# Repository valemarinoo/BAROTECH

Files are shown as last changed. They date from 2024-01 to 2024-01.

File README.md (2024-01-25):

# BAROTECH PROJECT README

Welcome to the Barotech Project! This repository contains essential files and documentation for the development of a Low Power, Low Cost BLE (Bluetooth Low Energy) device designed for Barometric Pressure monitoring. Below is a guide on the contents of this repository and how to navigate through them.

## Folder Structure:

### 1. Allegro folder
- **.brd file:** PCB layout design file for the Barotech device.

### 2. Capture_CIS folder
- **OrCAD circuit schematics:** Schematic diagrams created in OrCAD Capture CIS for the circuit.

### 3. Eurocircuits folder
- **Validation and Evaluation files:** Provided by Eurocircuits for project cost analysis. Includes files for 1, 10, 100, and 1000 PCBs.

### 4. Gerber folder
- **Gerber files:** Files exported from Allegro for manufacturing validation and evaluation.

### 5. MY_ORCAD_LIBRARY folder
- **Library files:** Used for the symbols in the project.

### 6. PADSTACKS folder
- **.pad files:** Created/modified for the components' padstacks.

### 7. FOOTPRINTS folder
- **.dra files:** Created/modified for the components' footprints.

### 8. Schematics folder
- **PDFs:** OrCAD circuit schematic exported from Capture CIS.

### 9. BOM
- **Excel file:** Project's Bill Of Material, detailing each used component (vendor details, value, mounting type, manufacturer, unit price).

### 10. MOVIE
- **Video:** A brief video providing an overview of the Barotech Project and demonstrating the usage of the main tools.

### 11. Technical_Report
- **Technical report:** Detailed documentation covering the project's design history, features, and final implementation.

## How to Use:

1. **PCB Layout:** Open the .brd file in the Allegro folder for the PCB layout.

2. **Circuit Schematics:** Review the OrCAD circuit schematics in the Capture_CIS folder.

3. **Validation and Evaluation:** Explore the Eurocircuits folder for files required for manufacturing validation and cost analysis.

4. **Gerber Files:** Access manufacturing files in the Gerber folder exported from Allegro.

5. **Library Files:** Find symbol library files in the MY_ORCAD_LIBRARY folder.

6. **PADSTACKS and FOOTPRINTS:** Explore .pad and .dra files in the respective folders for component padstacks and footprints.

7. **Schematic PDFs:** View the exported OrCAD circuit schematic PDFs in the Schematics folder.

8. **Bill Of Material:** Open the BOM Excel file for detailed information on each used component.

9. **Video:** Watch the MOVIE for a brief overview of the project and tool usage.

10. **Technical Report:** Refer to the Technical_Report for a comprehensive understanding of the project's design and implementation.

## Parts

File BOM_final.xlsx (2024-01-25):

Item # | Quantity Per Board | Manufacturer Part # | Do Not Install | Reference Designators | Vendor | Vendor Part Number | Value | Mounting type | Part Description | Manufacturer | UNIT PRICE
1 | 1 | / | / | A1 | / | / | 50 Ohms | / | 50 Ohm Antenna | /
2 | 8 | KGM32HR72D104KU | / | C1,C2,C6,C7,C9,C11,C12,C18,C22 | Digikey | 478-KGM32HR72D104KUTR-ND | 100nF | SMD | Multilayer Ceramic Capacitors MLCC - SMD/SMT 200V .1uF X7R 1210 10% | KYOCERA AVX | 0.49 €
3 | 3 | KGM32ER71H105KU | / | C3,C16,C17 | Digikey | 478-KGM32ER71H105KUTR-ND | 1uF | SMD | Multilayer Ceramic Capacitors MLCC - SMD/SMT 50V 1uF X7R 1210 10% | KYOCERA AVX | 0.41 €
4 | 3 | KGQ32DCG2A120KT | / | C4,C5,C15 | Mouser | 581-12101U120KAT2A | 12pF | SMD | Multilayer Ceramic Capacitors MLCC - SMD/SMT 100V 12pF C0G 1210 10% | KYOCERA AVX | 0.50 €
5 | 4 | KGM32LR71E106KU | / | C8,C10,C19,C21 | Digikey | 478-KGM32LR71E106KUTR-ND | 10uF | SMD | Multilayer Ceramic Capacitors MLCC - SMD/SMT 25V 10uF X7R 1210 10% | KYOCERA AVX | 0.70 €
6 | 2 | C1210C129D8HACTU | / | C13,C14 | Mouser | 80-C1210C129D8HACTU | 1.2pF | SMD | Multilayer Ceramic Capacitors MLCC - SMD/SMT 10V 1.2pF X8R 1210 0.5pF | KEMET | 0.18 €
7 | 1 | C1210C334K5RAC7800 | / | C20 | Digikey | C1210C334K5RAC7800 | 330nF | SMD | Multilayer Ceramic Capacitors MLCC - SMD/SMT .33UF 50V 10% 1210 | KEMET | 0.60 €
8 | 1 | 19-337C/RSBHGHC-A88/4T | / | D1 | Digikey | 1080-1631-2-ND | LED RGB | SMD | LED RGB CLEAR 6SMD | Everlight Electronics Co Ltd | 0.59 €
9 | 1 | BLM18HE152SN1D | / | FB1 | Digikey | 490-5216-2-ND | BLM18HE152SN1D | SMD | Ferrite Beads 1500 Ohm 25% SMD | Murata Electronics | 0.17 €
10 | 1 | BMP390 | / | IC1 | Mouser | 262-BMP390 | BMP390 | SMD | Board Mount Barometric Pressure Sensor High Performance | Bosch Sensortec | 3.67 €
11 | 1 | MAX1759EUB+ | / | IC2 | Digikey | MAX1759EUB+-ND | MAX1759EUB+ | SMD | Switching Voltage Regulators Buck/Boost Regulating Charge Pump in MAX | Maxim Integrated | 6.91 €
12 | 1 | FTSH-105-01-L-D-RA-K | / | J1 | Digikey | SAM9437-ND | FTSH-105-01-L-D-RA-K | SMD | Connector Header Through Hole, Right Angle 10 position 0.050" (1.27mm) | Samtec Inc. | 1.77 €
13 | 1 | B2B-PH-K-S | / | J2 | Digikey | 455-1704-ND | B2B-PH-K-S | SMD | Connector Header Through Hole 2 position 0.079" (2.00mm) | JST Sales America Inc. | 0.17 €
14 | 1 | 1051640001 | / | J3 | Digikey | WM11263TR-ND | 105164-0001 | SMD | micro B USB 2.0 Receptacle Connector 5 Position Surface Mount, Right Angle; Through Hole | Molex | 0.94 €
15 | 1 | BRL3225T100K | / | L1 | Digikey | 587-2167-2-ND | 10uH | SMD | Fixed inductor 10uH 700mA 420mOhm SMD | Taiyo Yuden | 0.20 €
16 | 1 | NLV32T-015J-EF | / | L2 | Digikey | 445-16528-2-ND | 15nH | SMD | RF Inductors - SMD 15nH 160mohms 450mA Wound Ferrite | TDK Corporation | 0.20 €
17 | 1 | LQG15HN2N0S02D | / | L3 | Digikey | 490-6558-2-ND | 2nH | SMD | RF Inductors - SMD 2 NH +-.3NH | Murata Electronics | 0.09 €
18 | 2 | CRCW121010K0JNEA | / | R1,R2,R4 | Digikey | 541-10KVTR-ND | 10 kOhm | SMD | Thick Film Resistors - SMD 1/2watt 10Kohms 5% | Vishay Dale | 0.20 €
19 | 1 | CRCW1210100KFKEA | / | R3 | Digikey | 541-100KAATR-ND | 100 kOhm | SMD | Thick Film Resistors - SMD 1/2watt 100Kohms 1% | Vishay Dale | 0.23 €
20 | 2 | CRCW12103K30JNEA | / | R14 | Digikey | 541-3.3KVTR-ND | 3.3 kOhm | SMD | Thick Film Resistors - SMD 1/2watt 3.3Kohms 5% | Vishay Dale | 0.20 €
21 | 4 | CRCW121033K0JNEA | / | R5,R6,R7,R8 | Digikey | 541-33KVTR-ND | 33 kOhm | SMD | Thick Film Resistors - SMD 1/2watt 33Kohms 5% | Vishay Dale | 0.20 €
22 | 1 | CRCW1210200RFKEA | / | R9 | Digikey | 541-200AATR-ND | 200 Ohm | SMD | Thick Film Resistors - SMD 1/2watt 200ohms 1% | Vishay Dale | 0.23 €
23 | 1 | CRCW121082R0JNEA | / | R10 | Digikey | 541-82VTR-ND | 82 Ohm | SMD | Thick Film Resistors - SMD 1/2watt 82ohms 5% | Vishay Dale | 0.20 €
24 | 1 | CRCW1210110RJNEA | / | R11 | Digikey | 541-CRCW1210110RJNEATR-ND | 110 Ohm | SMD | Thick Film Resistors - SMD 1/2watt 110ohms 5% | Vishay Dale | 0.20 €
25 | 2 | CRCW121022R0JNEA | / | R12,R13 | Digikey | 541-22VTR-ND | 22 Ohm | SMD | Thick Film Resistors - SMD 1/2watt 22ohms 5% | Vishay Dale | 0.20 €
26 | 1 | CRCW1210330RFKEA | / | R15 | Digikey | 541-330AATR-ND | 330 Ohm | SMD | Thick Film Resistors - SMD 1/2watt 330ohms 1% | Vishay Dale | 0.23 €
27 | 1 | LL3301NF065QG | / | S1 | Digikey | EG5897TR-ND | LL3301NF065QG | SMD | Tactile Switches 50mA 12VDC F065 4.3mm Gull Wing | E-Switch | 0.67 €
28 | 1 | TL3901AGQF180 | / | S2 | Digikey | EG6068TR-ND | TL3901AGQF180 | SMD | Tactile Switches TactSwtch 12VDC 50mA | E-Switch | 0.95 €
29 | 1 | CC2640R2FRHBR | / | U1 | Digikey | 296-47317-2-ND | CC2640R2FRHBR | SMD | RF Microcontrollers - SimpleLink™ 32-bit Arm® Cortex®-M3 Bluetooth® 5.1 Low Energy wireless | Texas Instruments | 4.62 €
30 | 1 | MAX1555EZK+T | / | U2 | Digikey | MAX1555EZK+TTR-ND | MAX1555EZK+T | SMD | Battery Management SOT23, Dual-Input, USB/AC Adapter, 1-Cell Li+ Battery Chargers | Maxim Integrated | 2.45 €
31 | 1 | MAX17048G+T10 | / | U3 | Digikey | MAX17048G+T10TR-ND | MAX17048G+T10 | SMD | Battery Management 3 A 1-Cell/2-Cell Fuel Gauge with ModelGauge | Maxim Integrated | 3.09 €
32 | 1 | SC32S-7PF20PPM | / | Y1 | Digikey | 728-1074-2-ND | 32.768 kHz | SMD | 32.768 kHz ±20ppm Crystal 7pF 70 kOhms 2-SMD, No Lead | Seiko Instruments | 0.35 €
33 | 1 | XRCGB24M000F3M00R0 | / | Y2 | Digikey | 490-5576-2-ND | 24MHz | SMD | 24 MHz ±30ppm Crystal 6pF 150 Ohms 4-SMD, No Lead | Murata Electronics | 0.28 €
33 | 1 | L502030 | / | - | TME | ACCU-LP502030/CL | 250mAh | / | Rechargable Li-Po battery: 3.7V; 250mAh; cables,JST SYR-02T socket | Cellevia Batteries | 4.79 €
 |  |  |  |  |  |  |  |  |  |  | TOTALE
 |  |  |  |  |  |  |  |  |  |  | 36.68 €

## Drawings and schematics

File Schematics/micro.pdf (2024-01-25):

## MICROCONTROLLER

# U1 CC2640R2FRHBR

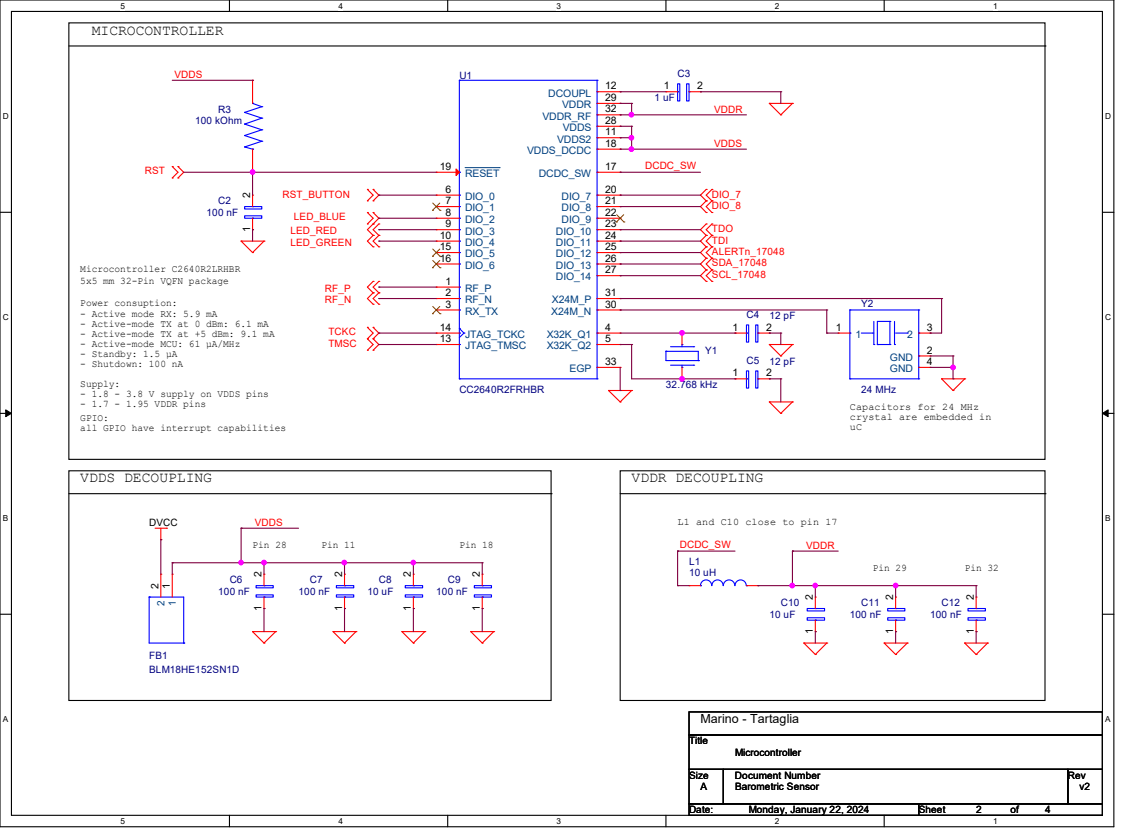
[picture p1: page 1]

Microcontroller C2640R2LRHBR
5x5 mm 32-Pin VQFN package

Power consuption:
- Active mode RX: 5.9 mA
- Active-mode TX at 0 dBm: 6.1 mA
- Active-mode TX at +5 dBm: 9.1 mA
- Active-mode MCU: 61 µA/MHz
- Standby: 1.5 µA
- Shutdown: 100 nA
Supply:
- 1.8 - 3.8 V supply on VDDS pins
- 1.7 - 1.95 VDDR pins
GPIO:
all GPIO have interrupt capabilities DVCC

Capacitors for 24 MHz
crystal are embedded in

L1 and C10 close to pin 17

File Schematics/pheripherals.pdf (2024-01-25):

## ANTENNA

### Antenna for single ended operations

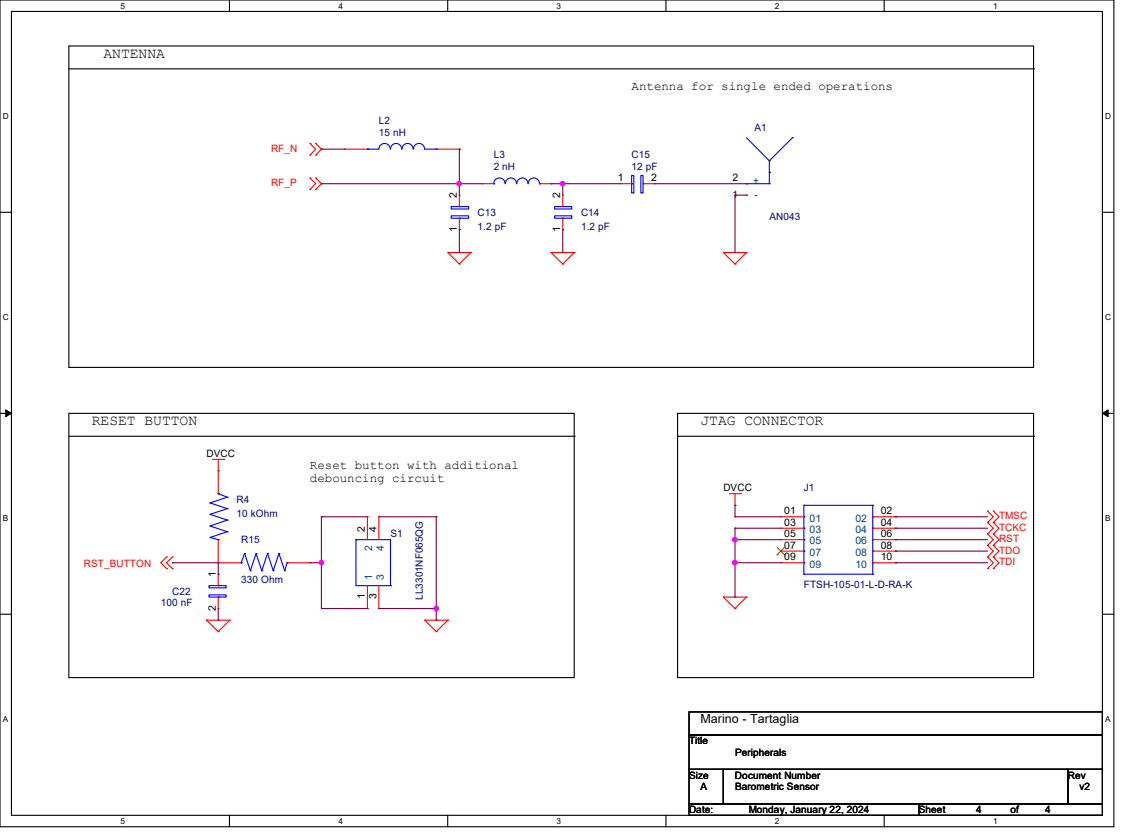
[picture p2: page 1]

Reset button with additional
debouncing circuit

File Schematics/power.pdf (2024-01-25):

## BATTERY CONNECTOR

BATTERY CHARGER | Vf of RGB LED is:

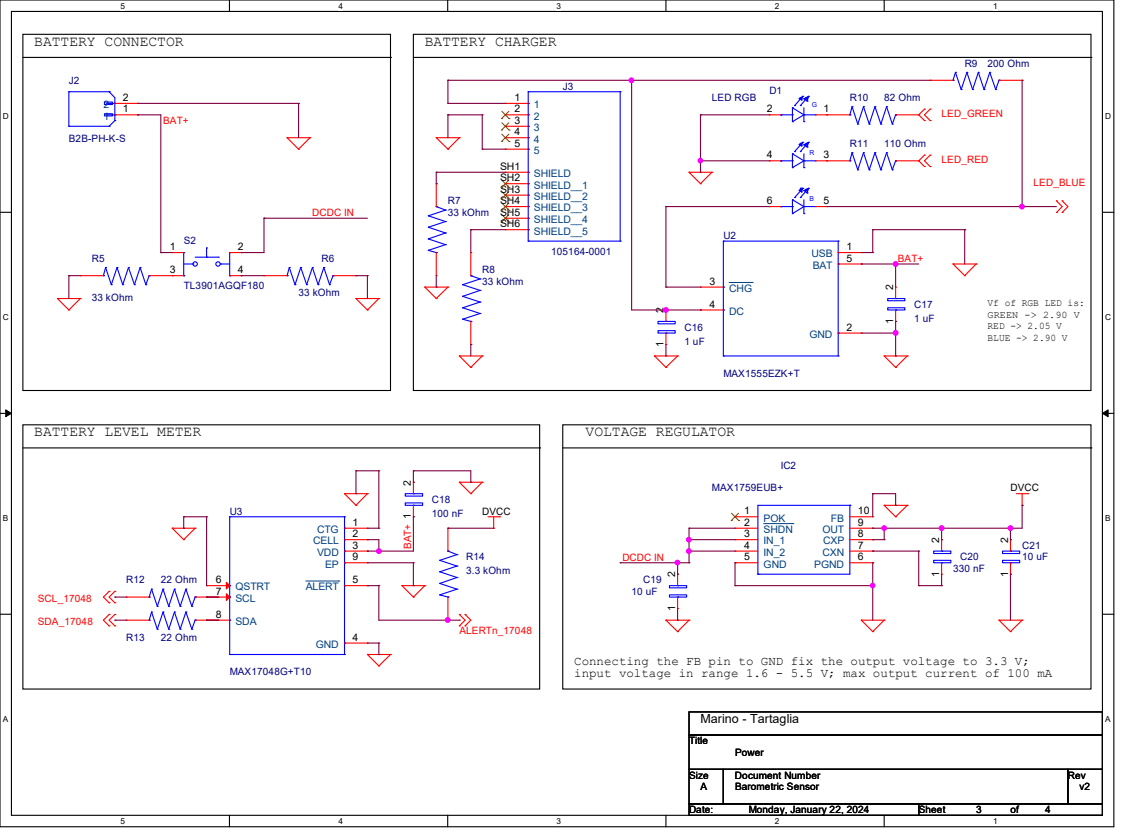
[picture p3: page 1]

2 U3 MAX17048G+T10 CTG 1 CELL 2 VDD 3 GND 4 ALERT 5 QSTRT 6 SCL 7 SDA 8 EP 9

Connecting the FB pin to GND fix the output voltage to 3.3 V;
input voltage in range 1.6 - 5.5 V; max output current of 100 mA

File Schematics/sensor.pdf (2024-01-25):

## BAROMETRIC SENSOR

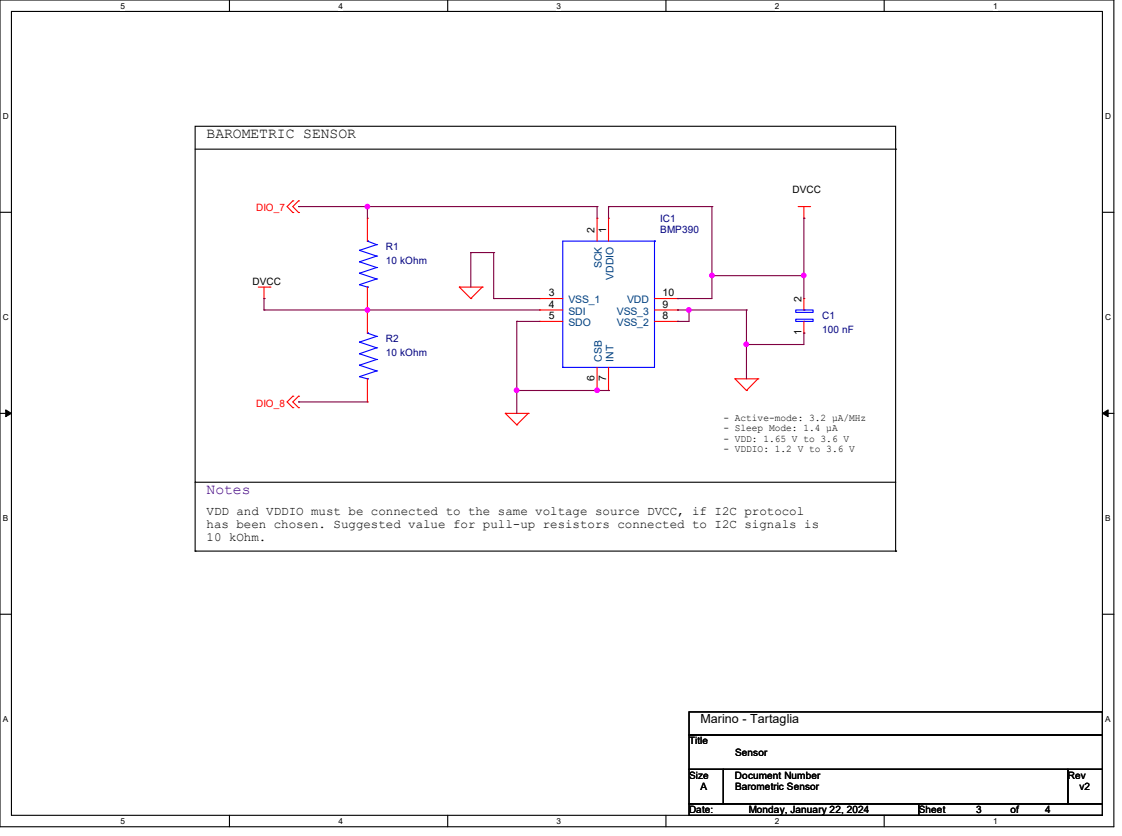
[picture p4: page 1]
Marino - Tartaglia; DVCC; DIO_7; DIO_8; Title Size; Document Number; Rev Date:; Sheet; of Barometric Sensor; v2 Sensor A; Monday, January 22, 2024; 4 Title Size; R1 10 kOhm; IC1 BMP390 VDDIO 1 SCK; 6 INT; 7 VSS_2 8 VSS_3 9 VDD 10 R2; 10 kOhm

2 VSS_1 3 SDI 4 SDO 5 CSB

- Active-mode: 3.2 µA/MHz
- Sleep Mode: 1.4 µA
- VDD: 1.65 V to 3.6 V
- VDDIO: 1.2 V to 3.6 V

Notes
VDD and VDDIO must be connected to the same voltage source DVCC, if I2C protocol
has been chosen. Suggested value for pull-up resistors connected to I2C signals is
10 kOhm.

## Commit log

2024-01-25 uploading project files
    [BAROTECH.DSN, BAROTECH.brd, cases.cfg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]
2024-01-25 uploading BOM file, updating README
    [BOM_final.xlsx]
